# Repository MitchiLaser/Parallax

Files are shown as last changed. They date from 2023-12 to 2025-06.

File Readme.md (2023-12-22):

# Parallax

Parallax is a cheap and simple but also powerful data acquisition system. The core of this device is a Raspberry Pi Pico which has multiple analog-to-digital converters. These can be used to measure analog voltages and stream the data directly to a PC for further processing and storing.

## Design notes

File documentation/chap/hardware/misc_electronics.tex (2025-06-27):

\section{Further electrical components and their usage}

\subsection{Voltage clamping with Diodes}

A Diode is a semiconductor device that allows current to flow in one direction only\footnote{This is technically not true because a diode can also let current flow in the opposite direction but this aspect is not necessary for the design described in this report}. When a Voltage is applied across the two terminals in the forward direction the current flows easily while in reverse direction the diode blocks current. In the forward direction current flows only if the applied voltage exceeds a threshold limit, the forward voltage, typically around $\SI{0.6}{V}$ to $\SI{0.7}{V}$ for standard silicon diodes. This also means that in forward direction a voltage has a constant voltage drop which is equal to its forward voltage.

Regularly a diode can be used to prevent large voltage spikes from damaging sensitive electronic components, either by clamping the voltage to a safe level or by redirecting the current away from sensitive parts of the circuit. This is often done in power supply circuits to protect against overvoltage conditions. \cref{fig:clamping-diodes} illustrates this: When the signal line is below $\SI{0}{V}$ current flows directly to ground from $D_2$. Similar, when the signal line exceeds the supply voltage $V_{cc}$, $D_1$ conducts. However this only works when the input impedance of the device $U_{out}$ is connected to is lower than the resistance across the diode. This clamping actions maintains the voltage within a defined range.

\begin{figure}[htb]
	\centering
	\begin{tikzpicture}
		\draw (0,0) node[ground] {} 
			to[sV, l=$U_{in}$] ++ (0,2)
			-- ++ (0.5,0)
			-- ++ (2,0) node {$\bullet$} coordinate (A)
			to[short, -o] ++ (1,0) node[right] {$U_{out}$}
			(A) to[Do, l=$D_1$] ++ (0,2)
			node[vcc] {$V_{cc}$}
			(A) ++ (0,-2) node[ground] {}
			to[Do, l=$D_2$] (A)
		;
	\end{tikzpicture}
	\caption{A visualisation of the usage of clamping diodes}
	\label{fig:clamping-diodes}
\end{figure}

There is one disadvantage when this circuit is build with normal diodes: The voltage between the two terminals must be greater than the forward voltage. In this Example the voltage can only be clamped between $\SI{-0,7}{V}$ and $V_{cc} + \SI{0,7}{V}$. Diodes with a smaller forward voltage reduce this gap and here Schottky diodes are the better choice. Normal diodes are build by combining a p-type and a n-type doped semiconductor. Schottky diodes are just a combination of a doped semiconductor and a raw piece of metal. This construction has faster switching times and lower forward voltages, down to $\SI{0,3}{V}$.

After some more thinking the clamping didoes were removed from the design for the following reasons:
\begin{itemize}
	\item The clamping didoes chosen for this design were Schottky diodes. Unfortunately these have a relatively high leakage current which messes up the measurement for the smallest input range.
	\item The input current maximum rating of the ADC is only exceeded for input voltages larger than \SI{300}{V}, which should never happen under normal operating conditions. For ESD protection, the Op-Amp's internal clamping diodes are sufficient.
	\item The ADC's input cannot exceed the supply voltage $V_{cc}$ and $GND$ of the Op-Amp.
\end{itemize}

\subsection{Analog Multiplexers}

An analog multiplexer is an electronic component acting like a switch, routing multiple signals and a common input or output. Only one of the terminals can be connected at a time. Selection occurs via input signal lines which determine the connected terminal by the binary representation of its terminal number.

On the oscilloscope a multiplexer switches between resistors which are connected to ground. This makes the gain of a non-inverting amplifier variable across pre-defined configurations.

\subsection{Low pass filters}

A low pass filter is a combination of a resistor and a capacitor as depicted in \cref{fig_lowpass}. When a high frequency signals comes into this circuit form the left side then the capacitor is charged. This results in a smothering of the input signal. A low frequency signal gets less distorted than a high frequency signal.

\begin{figure}[htb]
	\centering
	\begin{tikzpicture}
		\draw (0,0) -- ++ (0.5,0)
			to[resistor, l=$R$] ++ (2,0)
			-- ++ (0.5,0)
			to[capacitor, l=$C$, *-] ++ (0,-1.5)
			node[ground] {}
			++ (0,1.5) -- ++ (1,0)
		;
	\end{tikzpicture}
	\caption{Low-Pass filter}
	\label{fig_lowpass}
\end{figure}

This circuit can be used to filter out some high frequency parts of a signal above the cutoff frequency:
\[
f = \frac{1}{2 \cdot \pi \cdot R \cdot C}\,.
\]
A low pass filter is going to be used to remove unwanted higher order frequency components of the input signal and removes aliasing effects. The reason for them is the Nyquist-Shannon theorem which in simple terms says that the highest with an oscilloscope measurable frequency is half of the sampling rate.

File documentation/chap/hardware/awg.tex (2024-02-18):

% todo: This document was not cheak-read yet.
\section{Signal Generator}

The Data Acquisition system should be extended by a arbitrary waveform generator which consists of a Digital to Analog Converter (DAC) and an amplification stage. This can be used to generate arbitrary signals: Sine-waves, triangular or rectangular periodical voltages with an adjustable frequency and amplitude. This enables students to explore and understand concepts in waveform generation, frequency modulation and signal processing and enhances the oscilloscope with a signal source. Many lab curse experiments can benefit from that e.g. measuring the frequency response of RC components, inductances or analysing the behavior or transistors and op-amps.

There are multiple ways how to create a waveform generator but then main structure is made out of three components. At first a analog voltage needs to be generated by a DAC. The DAC might need a buffer to provide an output current which can be achieved by using a buffer op-amp. At this point some amplification of the signal can be used to increase or decrease the magnitude of the signal. Finally this is used to drive an output stage in order to provide enough current for practical applications. Some of these components or even combinations of them can be bought as integrated circuits whereas others can be self made from simple building blocks. Many combinations might lead to the same result but the goal of this project is to make a cheap and simple signal generator without paying too much attention at a high precision (8 Bit resolution should be enough) or driving high frequencies\footnote{Note from the author: Initially I wished for a good signal generator but in the end I decided to go this way because it is cheaper by a couple euros.}. Therefore after a long time of researching components the way to go is: Using a R2R Ladder structure to turn 8 GPIO Pins from the Raspberry Pi Pico into a DAC and finding an Op-Amp which can provide enough current to drive a $\SI{50}{\Omega}$ signal line.

\subsection{R2R-Ladder DAC}

The DAC is a self-made R2R Ladder Structure which is driven by some parallel connected GPIO Pins. A Diagram for a 4-Bit DAC can be seen in \cref{fig:r2r-ladder}.

\begin{figure}[htb]
	\centering
	\begin{tikzpicture}
		\pgfmathsetmacro{\num}{4} % number of resistor-network stages
		\pgfmathtruncatemacro{\numminusone}{\num-1}
		\pgfmathtruncatemacro{\numminustwo}{\num-2}
		\foreach \i in {0, ..., \numminustwo} {
			\draw (\i * 2,0) to[resistor, l=$2R$, *-] ++ (0,2)
			node[above] {$B_{\i}$}
				++ (0,-2) to[resistor, l=$R$] ++ (2,0)
			;
		}
		\draw (0,0) to[resistor, l=$2R$] ++ (0,-2)
			node[ground] {}
			(\numminustwo * 2 + 2,0) to[resistor, l=$2R$, *-] ++ (0,2)
			node[above] {$B_{\numminusone}$}
			++ (0,-2) to[short, -*] + (1,0)
			node[right] {$U_{DAC}$}
		;
	\end{tikzpicture}
	\caption{R2R Ladder structure for a 4-Bit DAC}
	\label{fig:r2r-ladder}
\end{figure}

A detailed explanation how this DAC is working would take away some pages in this document so this explanation is going to cover only a rough overview. Any of the inputs $U_x$ can be set to a logical $1$ or a logical $0$ which is equivalent to connect the input to the supply voltage $V_{cc}$ or GND. If only the most significant bit (most right) is set then all the other bits (on the left side) are connected to ground. The last digit ($B_0$) has two parallel resistors with a Value of $2R$ connected to ground, resulting in a Thevenin Equivalent circuit of a Grounding with a Thevenin resistance of $2R \parallel 2R = R$. After that the first resistor $R$ follows in series from where on both resistors are equivalent to $2R$. From there on the next Bit ($B_1$) is equally connected as the previous one before constructing the Thevenin Equivalent which means that the Thevenin Equivalent for all following zeroed Bits is the same. When we reach the first positive bit (in this case the highest order bit) the equivalent circuit is a voltage divider from $V_{cc}$ (the positive bit) to Ground via two $2R$ resistors and this results in an output voltage of $U_{DAC} = V_{cc} \cdot \frac{2R}{2R + 2R} = \frac{V_{cc}}{2}$ and a Thevenin resistance of $R$.

Let's assume that all bits are zero except for the second largest one. In this case again all the previous zeroed bits have a Thevenin equivalent of a grounded Connection with a resistance of $2R$ (Thevenin Resistance + R in series from the ladder) and the equivalent circuit of the positive bit is, as calculated before, $\frac{V_{cc}}{2}$ for the second largest bit. Following the resistor chain now the last bit, which is set to $0$, creates a second attenuator with the resistors $2R$ in series to $2R$. This halves the voltage again to $\frac{V_{cc}}{4}$ and keeps the Thevenin resistance still at $R$.

This principle applies for all the other bits. Now we can apply the principle of superposition: All currents from the input Bits flowing towards the output sum up. The DAC output voltage can therefore be described as follows:
\[
U_{DAC} = \sum_{i = 1}^N \frac{V_{cc}}{i + 1}
\]
When all Bits are turned on for a 3-Bit DAC then the output voltage is
\[
	U_{DAC} = \frac{V_{cc}}{2} + \frac{V_{cc}}{4} + \frac{V_{cc}}{8} = V_{cc} \cdot \frac{7}{8}\,.
\]
Unfortunately a R2R ladder DAC can never generate the full supply voltage $V_{cc}$ at its output but with a higher Bit resolution the difference shrinks to a negligibly small size. The R2R ladder generates the voltage but as in all previously explained situations the important rule for resistor networks also applies here: Drawing current changes the behavior of the network. Therefore again a combination of buffers and amplifiers, especially to create a output driver with a predefined impedance.

Last but not least a low-pass filter is useful to suppress aliasing effects. The R2R ladder has an output impedance equal to $R$ so the only missing thing is to add a capacitor with the right size. To keep the output stage as simple as possible a voltage follower is made of an op-amp which can drive enough current to drive a $\SI{50}{\Omega}$ output. At a maximum voltage of $\SI{3,3}{V}$ the expected current is less than $\SI{70}{mA}$. For the frequency we can expect that in the fastest operation mode at $\SI{125}{MSps}$ a sine wave constructed from 64 samples\footnote{This is just an assumption without any technical background} stays below a frequency of $\SI{5}{MHz}$. The only challenge here is to find a device which has these capabilities (output current and unity-gain bandwidth) but is still cheap.

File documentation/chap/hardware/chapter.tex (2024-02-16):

\chapter{Hardware Design}

\input{./chap/hardware/introduction.tex}
\input{./chap/hardware/adc.tex}
\input{./chap/hardware/voltage_divider.tex}
\input{./chap/hardware/op-amp.tex}
\input{./chap/hardware/misc_electronics.tex}
%\input{./chap/hardware/awg.tex}
\input{./chap/hardware/schematics.tex}

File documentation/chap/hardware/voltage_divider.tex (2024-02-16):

\section{Voltage Divider}

One of them most important circuits in electronics is the voltage divider, depicted in \cref{fig:simple-voltage-divider}. In this circuit two resistors $R_1$ and $R_2$ are between connected in series between a voltage source $V_{cc}$ and Ground. Since it's a closed circuit there's a current flowing through the resistors and each resistor causes an individual voltage drop. Can we calculate the voltage $U_o$ between these two resistors?

It's easy to see that the current flowing in this circuit is the same for both resistors. When two resistors are connected in series their resistances add up and this total resistance can be used to calculate the current with Ohms law:
\begin{equation*}
	I = \frac{U}{R} = \frac{V_{cc}}{R_1 + R_2}\,.
\end{equation*}
We also know that the voltage drop $U_1$ across $R_1$ and the voltage drop $U_2$ across $R_2$ add up to the supply voltage: $U_1 + U_2 = V_{cc}\,$. The voltage drop across $R_2$ can be calculated using Ohm's law again because we know the current and the resistance:
\begin{equation*}
	U_2 = R \cdot I = V_{cc} \cdot \frac{R_2}{R_1 + R_2}\,.
\end{equation*}
A similar behavior can be seen for $R_1$:
\begin{equation*}
	U_1 = R \cdot I = V_{cc} \cdot \frac{R_1}{R_1 + R_2}\,.
\end{equation*}

This shows us that we can calculate the voltage $U_o = U_2 = V_{cc} - U_1$ between the resistors. It's independent of the total current and only depends on the ratio of the two resistors. It wouldn't make a difference if we use $R_1 = \SI{10}{K\Omega}, R_2 = \SI{2,2}{K\Omega}$ or $R_1 = \SI{10}{\Omega}, R_2 = \SI{2,2}{\Omega}$, the result would be the same.

\begin{figure}[htb]
	\centering
	\begin{tikzpicture}
		\draw (0,0) node[ground] {}
			to[resistor, l=$R_2$, -*] ++ (0,2) coordinate (A)
			to[short, -o] ++ (1,0)
			node[auto, anchor=west] {$U_o$}
			(A) to[resistor, l=$R_1$] ++ (0,2)
			node[vcc] {$V_{cc}$}
		;
	\end{tikzpicture}
	\caption{A voltage divider made with two resistors}
	\label{fig:simple-voltage-divider}
\end{figure}

The characteristic equation to describe a voltage divider can be seen in \cref{equ:resistive-voltage-divider}:
\begin{equation}
	\frac{U_1}{U_2} = \frac{R_1}{R_2}\,.
	\label{equ:resistive-voltage-divider}
\end{equation}

We can use this circuit to reduce a voltage but its usability as a voltage source is limited. This can be shown in \cref{fig:loaded-voltage-divider} by adding a load, in this case a resistor $R_L$. Now the total resistance of the parallel resistors $R_2$ and $R_L$ calculates to
\begin{equation*}
	R_x = R_2 \parallel R_L = \frac{1}{\frac{1}{R_2} + \frac{1}{R_L}}
\end{equation*}
and the result of this is smaller than $R_2$ and $R_L$. The load changes the voltage divider and this changes the output voltage $U_o$.

\begin{figure}[htb]
	\centering
	\begin{tikzpicture}
		\draw (0,0) node[ground] {}
			to[resistor, l=$R_2$, -*] ++ (0,2) coordinate (A)
			to[short, -o] ++ (1,0) coordinate (B)
			node[auto, anchor=west] {$U_o$}
			(A) to[resistor, l=$R_1$] ++ (0,2)
			node[vcc] {$V_{cc}$}
			(B) to[resistor, l=$R_L$] ++ (0,-2)
			to[short, -*] ++ (-1,0)
		;
	\end{tikzpicture}
	\caption{A voltage divider with load resistance}
	\label{fig:loaded-voltage-divider}
\end{figure}

A voltage divider can only be used as a voltage source if there is no load attached to it. This means we cannot use it to drive an electric device but we will later see that there is a possibility to avoid this issue.

Right now we only have discussed what happens when we have a fixed voltage $V_{cc}$ driving this circuit. With an AC supply $U = U_0 \cdot \sin(\omega \cdot t)$ the voltage divider still works the same because only $V_{cc}$ is time dependent; the resistors are constant and independent from the voltage or the frequency of $V_{cc}$ and therefore it should work the same with AC and DC current.

\begin{figure}[htb]
		\centering
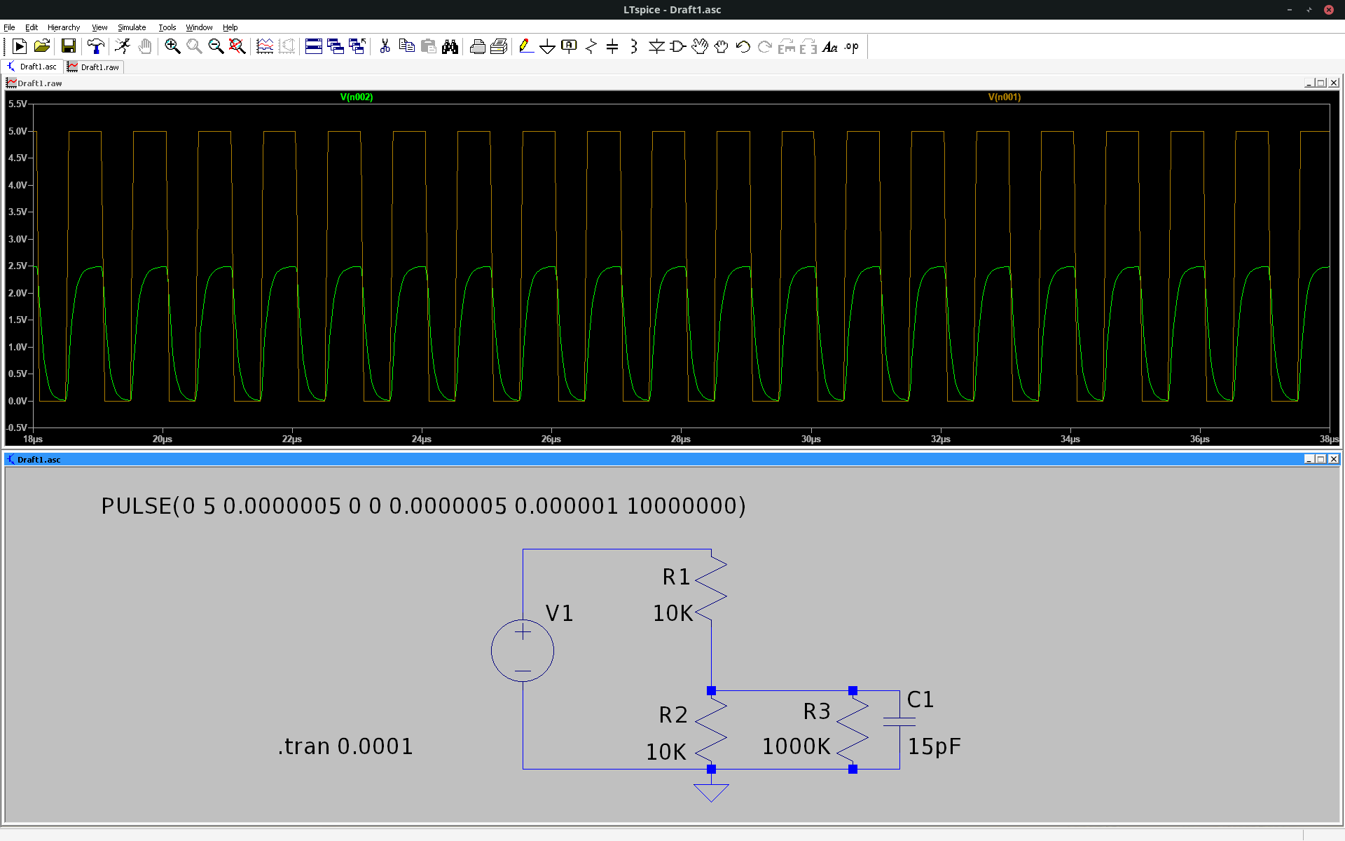
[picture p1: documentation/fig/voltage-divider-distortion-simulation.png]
		
		\caption{A square wave signal which is being disturbed by the input capacitance of an ADC}
		\label{fig:voltage-divider-distortion}
\end{figure}

Hold on! The last paragraph was partially a lie. In theory a resistor should only have a resistance but in reality every component has some resistance, capacitance and inductance. In many cases we can ignore the unwanted side-effects but when the circuit has to interact with high frequency signals these have to be taken into account. If we want to measure the voltage $U_o$ then our measurement device (which would be an ADC) has a large input resistance and a small input capacity. The large input resistance is good because ifs effect on the voltage divider can be neglected\footnote{You wanna know why? Calculate the reduction of an input voltage for a 1:1 voltage divider made out of $\SI{1}{K\Omega}$ resistors with and without an $R_L = \SI{10}{M\Omega}$ load.} but the small input capacitance would introduce a new side effect on this circuit. \cref{fig:voltage-divider-distortion} is a simulation of a square signal which will be distorted by the small input capacitance ($C_1 = \SI{15}{pF}$) of a measurement device (The large input resistance $R_3 = \SI{1}{M\Omega}$ was also taken into account in this simulation). Before we discuss how to deal with this side effect we will take a look on a voltage divider which is especially build for AC currents.

\subsection{The capacitive voltage divider}

For a DC voltage a capacitor is an impervious barrier but for an AC voltage the capacitor behaves like an electrical conductor which induces a phase shift of $\SI{90}{\degree}$. If we arrange two capacitors as seen in \cref{fig:capacitive-voltage-divider} and have an alternating voltage $\sim V_{cc}$ we can observe a similar behavior as with the resistor-based voltage divider in \cref{fig:simple-voltage-divider}.

\begin{figure}[htb]
	\centering
	\begin{tikzpicture}
		\draw (0,0) node[ground] {}
			to[C, l=$C_2$, -*] ++ (0,2) coordinate (A)
			to[short, -o] ++ (1,0)
			node[auto, anchor=west] {$U_o$}
			(A) to[C, l=$C_1$] ++ (0,2)
			node[vcc] {$\sim V_{cc}$}
		;
	\end{tikzpicture}
	\caption{A capacitive voltage divider}
	\label{fig:capacitive-voltage-divider}
\end{figure}

In this circuit the overall charge $Q$ through the capacitors is preserved:
\begin{equation*}
	Q = C \cdot U = C_1 \cdot U_1 = C_2 \cdot U_2\,
\end{equation*}
where $U_1$ and $U_2$ are the voltage drops across the capacitors $U_1$ and $U_2$. With the overall capacity of two capacitors in series:
\begin{equation*}
	C_x = \frac{1}{\frac{1}{C_1} + \frac{1}{C_2}} = \frac{C_1 \cdot C_2}{C_1 + C_2}
\end{equation*}
and the use of $Q = C_x \cdot V_{cc} = C_2 \cdot U_2$ the voltage $U_2$ drop across $C_2$ can be calculated:
\begin{equation*}
	U_2 = U_0 \frac{Q}{C} =  \frac{V_{cc}}{C_2} \cdot C_x = \frac{V_{cc}}{C_2} \cdot \frac{C_1 \cdot C_2}{C_1 + C_2} = V_{cc} \cdot \frac{C_1}{C_1 + C_2}
\end{equation*}
From symmetric reasons the equation for $U_1$ looks similar:
\begin{equation*}
	U_1 =  V_{cc} \cdot \frac{C_2}{C_1 + C_2}
\end{equation*}

From this the characteristic equation of the capacitive voltage divider is \cref{equ:capacitive-voltage-divider}

\begin{equation}
	\frac{U_1}{U_2} = \frac{C_2}{C_1}\,.
	\label{equ:capacitive-voltage-divider}
\end{equation}

With this knowledge we can build a voltage divider for AC signals but it cannot be used for DC voltages. Like a resistive voltage divider a capacitive one also only works when there is no load attached. A load can also be seen as an additional capacitor, similar to \cref{fig:loaded-voltage-divider}, which changes the capacitance ration and affects the voltage drop.

\subsection{Frequency compensated attenuator}

A resistive attenuator can only be used properly with DC voltages or AC voltages at low frequencies and a capacitive attenuator can be used with alternating voltages at high frequencies but is unusable for DC voltages. The solution to achieve both within a single circuit is called a "Frequency compensated attenuator" (\textit{attenuator} is just another name for a voltage divider).

\begin{figure}[htb]
	\centering
	\begin{tikzpicture}
		\draw (0,0) node[ground] {}
			to[short, *-] ++ (-2,0)
			to[resistor, l=$R_2$] ++ (0,2) coordinate (A)
			to[resistor, l=$R_1$, *-] ++ (0,2)
			-- ++ (2,0)
			node[vcc] {$V_{cc}$}
			to[short, *-] ++ (0,0)
			to[C, l=$C_1$, -*] ++ (0,-2) coordinate (B)
			to[C, l=$C_2$, -*] ++ (0,-2)
			-- ++ (-1,0)
			(B) ++ (2,0) coordinate (C)
			to[vC, l=$C_T$, *-] ++ (0,-2)
			to[short, -*] ++ (-2,0)
			(A) to[short] (B)
			to[short] (C)
			to[short, -o] ++ (1,0)
			node[auto, anchor=west] {$U_o$}
		;
	\end{tikzpicture}
	\caption{A frequency compensated attenuator with an adjustable capacitor for fine tuning}
	\label{fig:frequency-compensated-attenuator}
\end{figure}

The attenuator in \cref{fig:frequency-compensated-attenuator} is just a combination of a resistive voltage divider for DC signals and a capacitive voltage divider for AC signals in parallel. By using resistors which are way smaller than the load resistance of a measurement device the load would not affect this attenuator. The same thing happens when the capacitors are chosen large enough: a small load capacity would not effect the attenuator. There is also a trimmer capacitor which will be discussed later.

Let's take a look at the behaviour of this voltage divider first. We know the descriptive formulas of the previously discussed voltage dividers:
\begin{equation*}
	\frac{U_1}{U_2} = \frac{R_1}{R_2} = \frac{C_2}{C_1}
\end{equation*}
This means that a frequency compensated attenuator needs to fulfill the following requirements:
\begin{equation}
	R_1 \cdot C_1 = R_2 \cdot C_2\,.
	\label{equ:frequency-compensated-attenuator}
\end{equation}
This equation is essential for choosing the right components. One missing detail lies in the trimmer capacitor. Its only task is to compensate uncertainties of the components or other side effects which have not been taken into account. This trimmer capacitor can be set to its proper value in a calibration process until \cref{equ:frequency-compensated-attenuator} is satisfied. To do so the attenuator needs to be driven by a square signal. During a recording of $U_o$ the trimmer capacitor needs to be adjusted until the results show a pure square signal with no distortions.

\subsection{Adding voltages}

In \cref{fig:simple-voltage-divider} the voltage divider was constructed in a way where the second resistor was connected to ground. This makes it easy to calculate $U_o$ which is the voltage drop across $R_2$ added to the electrical potential at the other side of the resistor: $U_o = U_{Gnd} + U_2\,$. Since the grounding is just a fixed value for a potential this could also be set to an arbitrary value above or below Ground and the voltage divider would still work on the potential difference across the two resistors. We are going to abuse this effect to shape the output signal of the attenuator.

An ADC can only convert voltages from $\SI{0}{V}$ up to a reference voltage $U_{ref}$. To accept higher voltages than $U_{ref}$ an attenuator can be used to reduce the voltage by a factor which is specified by the resistor ratio. For voltages below the Ground of the ADC the only option is to shift the voltage up by adding a DC offset. Replacing the Ground potential at the attenuator with a Voltage source makes this voltage addition possible.

\begin{figure}[htb]
	\centering
	\begin{tikzpicture}
		\draw (0,0) node[vcc] {$V_+$}
			-- ++ (-1,0)
			to[resistor, l=$R_2$, -*] ++ (0,2) coordinate (A)
			to[short, -o] ++ (1,0)
			node[auto, anchor=west] {$U_o$}
			(A) to[resistor, l=$R_1$] ++ (0,2)
			-- ++ (1,0)
			node[vcc] {$V_{in}$}
		;
	\end{tikzpicture}
	\caption{Using an attenuator to add a DC offset to an input voltage}
	\label{fig:attenuator-voltage-adder}
\end{figure}

\cref{fig:attenuator-voltage-adder} is a schematic of this idea. This also works with a capacitive attenuator but for simplicity the calculations will only be done for a resistive attenuator. The overall voltage across both resistors has now changed from $V_{cc} - GND = V{cc} - \SI{0}{V} = V_{cc}$ to the new voltage $U = U_{in} - U_+$. The voltage drop across both resistors stays the same as before, just the input voltage needs to be replaced in this formula:
\begin{equation*}
	U_2 = U \cdot \frac{R_2}{R_1 + R_2} = (U_{in} - U_+) \cdot \frac{R_2}{R_1 + R_2}
\end{equation*}
but $U_2$ is only the voltage drop across $R_2$. We know that the electrical potential has a value of $U_+$ after the current coming from the input signal has passed $R_2$ and we know that it lost a voltage of $U_2$ on its way through $R_2$:
\begin{align*}
	U_o &= U_+ + U_2 = U_+ + (U_{in} - U_+) \cdot \frac{R_2}{R_1 + R_2} \\
		&= U_{in} \cdot \frac{R_2}{R_1 + R_2} + U_+ \left(1 - \frac{R_2}{R_1 + R_2}\right) \\
		&= U_{in} \cdot \frac{R_2}{R_1 + R_2} + U_+ \cdot \frac{R_1}{R_1 + R_2}\,.
\end{align*}
We have shown that this change to the attenuator adds a DC offset of $U_+ \cdot \frac{R_1}{R_1 + R_2}$ to the output voltage $U_0$. This can be used to transform an AC input signal from $\pm U_{in}$ to a range between $\SI{0}{V}$ and the reference voltage $U_{ref}$ of an ADC which makes the signal $\pm U_{in}$ measurable with an ADC. If we want to realise this idea we need to calculate the right values for the resistors and $U_+$.

For our usage we assume that we want to combine an attenuator with a reference Voltage $U_+$ to transform input signals from $\pm{}U_{in}$ which are way above and below the input range of an ADC into a measurable range from $\SI{0}{V}$ to $U_{Aref}$. We want to calculate the right resistor values and reference voltage for a given $\pm{}U_{in}$ and $U_{Aref}$. Therefore we have to take a look at the two cases $+U_{in}$ and $-U_{in}$ where the output voltage of the attenuator should match $U_{Aref}$ and $\SI{0}{V}$.

In the first case we want the maximum value $+U_{in}$ to be mapped to $U_{Aref}$:
\begin{align}
	U_{Aref} &= \lvert U_{in} \rvert \cdot \frac{R_2}{R_1 + R_2} + U_+ \cdot \frac{R_1}{R_1 + R_2} \\
	U_+ \cdot \frac{R_1}{R_1 + R_2} &= U_{Aref} - \lvert U_{in} \rvert \cdot \frac{R_2}{R_1 + R_2}
\end{align}
and in the second case the minimum value $-U_{in}$ to be equal to Gnd:
\begin{align}
	\text{Gnd} &= - \lvert U_{in} \rvert \cdot \frac{R_2}{R_1 + R_2} + U_+ \cdot \frac{R_1}{R_1 + R_2} \\
	U_+ \cdot \frac{R_1}{R_1 + R_2} &= \text{Gnd} + \lvert U_{in} \rvert \cdot \frac{R_2}{R_1 + R_2} = \lvert U_{in} \rvert \cdot \frac{R_2}{R_1 + R_2}\,.
	\label{equ:attenuator_with_offset_derivation}
\end{align}
For simplicity we set Ground to $\SI{0}{V}$ and we can combine the equations:
\begin{align}
	\lvert U_{in} \rvert \cdot \frac{R_2}{R_1 + R_2} &= U_{Aref} - \lvert U_{in} \rvert \cdot \frac{R_2}{R_1 + R_2} \\
	2 \cdot \lvert U_{in} \rvert \cdot \frac{R_2}{R_1 + R_2} &= U_{Aref} \\
	2 \cdot \lvert U_{in} \rvert &= U_{Aref} \cdot \frac{R_1 + R_2}{R_2} = U_{Aref} \cdot \left( \frac{R_1}{R_2} + 1 \right) \\
	2 \cdot \frac{\lvert U_{in} \rvert}{U_{Aref}} &= \frac{R_1}{R_2} + 1 \\
	\frac{R_1}{R_2} &= \frac{2 \cdot \lvert U_{in} \rvert}{U_{Aref}} - 1\,.
\end{align}
This equation shows us that, independent from the voltage shift we can choose a value for one resistor and get the implicit value for the other resistor. The value for the voltage shift can be calculated after the resistor values have been selected. This will be shown with a modification of \cref{equ:attenuator_with_offset_derivation}:
\begin{align}
	U_+ \cdot \frac{R_1}{R_1 + R_2} &= \lvert U_{in} \rvert \cdot \frac{R_2}{R_1 + R_2} \\
	U_+ &= \lvert U_{in} \rvert \cdot \frac{R_2}{R_1 + R_2} \cdot \frac{R_1}{R_1 + R_2} \\
			&= \lvert U_{in} \rvert \cdot \frac{R_2}{R_1}\,.
\end{align}
With these equations we can easily choose the right values for the resistors and the offset voltage when we have decided on the input voltages we want to measure with an ADC. The offset voltage can be provided with an Operational Amplifier.

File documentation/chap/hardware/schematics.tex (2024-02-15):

\section{Designing the schematics}

The whole Schematics can be seen in %\cref{}
. Each major component is treated as a submodule which will be explained in detail individually.

\todo[inline]{Add picture and explaination of main structure}

\subsection{Analog Front-End}

The analog front-end is responsible for the following operations:
\begin{itemize}
	\item \textbf{Signal Coupling}: The front-end may offer different coupling options such as AC coupling or DC coupling. AC coupling blocks DC components of the signal, allowing only the AC portion to be displayed. DC coupling allows both AC and DC components to be displayed.
	\item \textbf{Signal attenuation}: The input signal might be in a range too large for the ADC. Attenuation circuits  reduce the magnitude of the incoming signal to a level that can be properly processed.
	\item \textbf{Signal amplification}: The analog front-end includes an amplifier stage to increase the magnitude of small signals. This amplification is necessary to ensure that small signals can be accurately measured.
	\item \textbf{Input Range selection}: To achieve a good measurement quality the attenuation and amplification can be varied depending on a selected input range. This input range is going to be mapped to the voltages which are suitable for the ADC.
	\item \textbf{Clamping}: Clamping diodes fix the maximum and minimum voltage level of the input signals and saves electrical components from dangerous voltages. Furthermore they are a good ESD protection for the circuit.
	\item \textbf{Signal Filtering}: In order to keep the input signals within the Nyquist frequency range a low-pass filter reduces aliasing effects.
	\item \textbf{Input impedance matching}: It's crucial for the oscilloscope to present a high input impedance to the circuit under test to minimize loading effects. The front-end typically ensures impedance matching to prevent distortion of the measured signal due to the oscilloscope's presence in the circuit.
	\item \textbf{Calibration}: Some parts of the circuit may compensate for any inaccuracies introduced by the analog components or variations in manufacturing.
\end{itemize}

At first some global decisions have to be made: Which input ranges (and how many) are going to be available.

\todo[inline]{Explain how the schematics diagram works, how all values were calculated and why some test pins were placed on their locations. Maybe also write something about the pcb layout?}

\todo[inline]{Design the PCB in a way that the backside has no electronic parts but a silk screen of all the schematics (mirrored) and all the test points should also be on this side}

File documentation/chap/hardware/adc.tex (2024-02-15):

\section{Measuring analog voltages}

The main part of the data collection process is the PR2040 Microcontroller, which has built-in Analog-to-Digital Converters (ADCs). These ADCs convert electronic voltages ranging from Ground ($\SI{0}{V}$) to a reference voltage $U_{ref}$ into digital numbers, with a resolution set to 12 bits. This means the digital result from an ADC falls between $0$ and $2^{12} = 4096$. In theory this mapping should be proportional but in practise there are small uncertainties in this conversion process due to the resolution, as depicted in \cref{fig:ADC-Curve}. This figure shows that the uncertainty of a value acquired by an ADC is half the voltage corresponding to the least significant bit (LSB), which can be calculated as:

\begin{equation*}
	\sigma = \pm{} U_{ref} \cdot \frac{1}{2} \cdot \frac{1}{2^{resolution}} = \pm{} U_{ref} \cdot 2^{-(resolution + 1)}\,.
\end{equation*}

\begin{figure}[htb]
		\centering
		
		\caption{Conversion from an analog voltage do a digital number with an ADC}
		\label{fig:ADC-Curve}
\end{figure}

In practice, there are further reasons for short-term fluctuations in voltage which are bigger than the quantization uncertainty. Therefore, the proper uncertainty of an ADC in an electronic application can be determined through a  calibration process. A detailed explanation and characterisation of the Raspberry Pi Picos ADCs is available on \href{http://pico-adc.markomo.me/}{this website}.

The \href{https://datasheets.raspberrypi.com/rp2040/rp2040-datasheet.pdf}{data sheet} explains that four ADC channels (ADC0 to ADC3) are connected to GPIO Pins and the fifth ADC channel (ADC4) is connected to an internal temperature sensor. Notably the fourth channel ADC3 is connected to an onboard attenuator. This configuration is intended to be used to measure the VSYS voltage of the Raspberry Pi Pico board.

Each channel is linked to a single Analog-to-Digital Converter (ADC) through an internal switch, allowing the selection of one channel at a time. The shared ADC operates with a maximum sampling rate of 500 kilosamples per second (KSps). This sampling rate can be utilized for measuring voltages on a single channel at the full sampling speed (simplex). Alternatively, it can simultaneously measure two channels by periodically switching between them, effectively halving the sampling rate to 250 KSps per channel. The level of accuracy and sampling rate is sufficient for using the system as the core of a simple oscilloscope which periodically acquires ADC values and streams the data to another device for further processing.

An ADC can only measure voltages between $\SI{0}{V}$ and $U_{ref}$ but we aim to build an oscilloscope capable of measuring both positive and negative voltages within a range, for instance, $\vert U \vert > \SI{10}{V}$. To achieve this, an analog front-end is needed to map voltages from $-U_{max}$ to $+U_{max}$ into an analog voltage suitable for the ADC. Furthermore the input voltage range should be adjustable and there should be an over-voltage protection on the signal inputs. This allows for the measurement of higher voltages with less precision or lower voltages with higher precision.

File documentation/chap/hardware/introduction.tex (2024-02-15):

\section{Introduction}

This part explains how the measurement system's hardware works. It aims to make it clear why and how the hardware was designed. Basically, the hardware is meant to convert analog voltages with a high amplitude into smaller ones. Then, we can measure these smaller voltages using the PR2040 Microcontroller on the Raspberry Pi Pico Microcontroller board.

\subsection{Prerequisites}

Before we talk about how the analog front-end works and the different voltage ranges for the oscilloscope, you need to know some basics about electronics. This includes:

\begin{itemize}
	\item Understanding what Charge, Voltage, and Current are
	\item Knowing about electrical resistance, Ohm's Law, and how resistors work
	\item Learning about Capacitance and capacitors
	\item Knowing how to use a Diode and a Z-Diode
\end{itemize}

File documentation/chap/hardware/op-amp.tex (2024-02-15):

\section{Operational Amplifier}

Operational Amplifiers, or op-amps, are highly used active electronic component\footnote{Active components need a supply voltage whereas passive components don't need a connection to a power supply} due to their versatility. In this section only the topics relevant for the application of this project are discussed. Let's take a look at the operational amplifier in \cref{fig:op_amp}: It has two inputs, namely an inverting and a non-inverting one, along with an output.

\begin{figure}[htb]
	\centering
	\begin{tikzpicture}
		\draw (0,0) node[op amp] (opamp) {}
			(opamp.+) -- + (-0.5,0) node[left] {$U_+$}
			(opamp.-) -- + (-0.5,0) node[left] {$U_-$}
			(opamp.out) -- + (0.5,0) node[right] {$U_{out}$}
			(opamp.up) -- + (0,0.5) node[vcc] {$V_{cc}$}
			(opamp.down) -- + (0,-0.5) node[vee] {$V_{ee}$}
		;
	\end{tikzpicture}
	\caption{Operational Amplifier}
	\label{fig:op_amp}
\end{figure}

Op-amps are being used in a configuration where the output voltage is connected to an input which creates a feedback loop. The behavior of am ideal operational amplifier can be described by the \glqq{}golden Rules\grqq{}:
\begin{enumerate}
	\item No current flows into the inputs.
	\item The output strives to minimize the voltage difference between the two input pins to zero volts.
\end{enumerate}

These rules only apply within a feedback loop. It's important to notice that the first rule is just an approximation because the input resistance cannot be infinitely high, resulting in an input bias current in reality. We assume that this is true in our model to describe the functionality of an op-amp and for practical applications the input impedance can be looked up in the data sheet. There are two op-amp circuits being used for the oscilloscope: the voltage follower and the non-inverting amplifier.

\subsection{Op-Amp as a Voltage follower}

The voltage follower configuration, illustrated in \cref{fig:voltage-follower}, serves as an impedance converter or as a buffer.

\begin{figure}[htb]
	\centering
	\begin{tikzpicture}
		\draw (0,0) node[op amp] (opamp) {}
			(opamp.out) -- ++ (0.5,0) node[right] {$U_{out}$}
			(opamp.up) -- ++ (0,0.5) node[vcc] {$V_{cc}$}
			(opamp.down) -- ++ (0,-0.5) node[vee] {$V_{ee}$}
			(opamp.-) -- ++ (-0.5,0) node[left] {$U_-$}
			-- ++ (0,2)
			-| (opamp.out) node {$\bullet$}
			(opamp.+) ++ (-0.5,-1.5) node[ground] (gnd) {}
			(opamp.+) -- ++ (-0.5,0) node[left] {$U_+$}
			-- ++ (0,-0.5)
			to[sV, l_=$U_{in}$] (gnd)
		;
	\end{tikzpicture}
	\caption{Op-Amp as a Voltage follower}
	\label{fig:voltage-follower}
\end{figure}

In this setup, the output voltage mirrors the input voltage, serving as a buffer. The high input impedance of the op-amp enables voltage replication without drawing significant current from the source, while the low output impedance ensures efficient transmission of the replicated voltage.

An example illustrates the significance of this buffer: a voltage divider generates a reference voltage, but using it as a direct voltage source is impractical due to the voltage drop when attaching a load. Using a voltage follower, as shown in Figure \ref{fig:attenuator-buffer}, solves this issue and allows the voltage follower to supply current while maintaining an output voltage equivalent to the voltage divider's reference voltage. In this sketch the power supply connections of the op-amp have been left out. This is done a lot of times in circuits because the connection to a power supply is necessary for an op-amp and therefore has not to be specialised separately.

\begin{figure}[htb]
	\centering
	\begin{tikzpicture}
		\draw (0,0) node[op amp] (opamp) {}
			(opamp.-) -- ++ (0,1)
			-| (opamp.out) node {$\bullet$}
			-- ++ (0.5,0) node[right] {$U_{out}$}
			(opamp.+) -- ++ (-1,0) node {$\bullet$} coordinate (A)
			to[resistor, l=$R_1$] ++ (0,2) node[vcc] {$V_{cc}$}
			(A) ++ (0,-2) node[ground] {} to[resistor, l=$R_2$] (A)
		;
	\end{tikzpicture}
	\caption{Voltage follower as a buffer}
	\label{fig:attenuator-buffer}
\end{figure}

When the input voltage $V_{cc}$ is constant and has no time dependency it is recommended to add a capacitor at the non-inverting input of the op-amp. This would stabilize the voltage and filter out minor fluctuations and instabilities.

\subsection{Op-Amp as a non-inverting amplifier}

Amplification of input signals is another essential task for an op-amp. There are multiple ways to perform an amplification. Here the non-inverting amplifier circuit, represended in \cref{fig:non_inverting_amplifier} is going to be explained.

\begin{figure}[htb]
	\centering
	\begin{tikzpicture}
		\draw (0,0) node[op amp, noinv input up] (opamp) {}
			(opamp.out) -- ++ (1,0) node[right] {$U_{out}$}
			(opamp.out) ++ (0.5,0) node {$\bullet$}
			to[resistor, l=$R_1$] ++ (0,-2) node {$\bullet$} coordinate (A)
			to[resistor, l=$R_2$] ++ (0,-2) node[ground] (gnd) {}
			(A) -| (opamp.-)
			(opamp.+) -- ++ (-1,0)
			++ (0,-2) node[ground] (gnd) {}
			to[sV, l=$U_{in}$] ++ (0,2)
		;
	\end{tikzpicture}
	\caption{Op-Amp as a non-inverting amplifier}
	\label{fig:non_inverting_amplifier}
\end{figure}

How does this circuit work? Based on the rules of the ideal op-amp the inverting input voltage $U_-$ is going to match the voltage at the non-inverting input $U_+$. $U_+$ is determined by the voltage across the two resistors of the attenuator. Therefore we can set $U_0$ from \cref{fig:simple-voltage-divider} equal to the input voltage:
\begin{equation}
	U_{in} = U_{out} \cdot \frac{R_2}{R_1 + R_2}\,.
\end{equation}
This equation can be transformed to calculate $U_{out}$ based on an arbitrarily chosen $U_{in}$:
\begin{equation}
	U_{out} = U_{in} \cdot \frac{R_1 + R_2}{R_2} = U_{in} \cdot \left( 1 + \frac{R_1}{R_2} \right)\,.
\end{equation}
The amplification factor, formally known as the \glqq{}gain\grqq{}, cannot be lower than $\SI{1}{}$. For the oscilloscope this configuration can be used to amplify small signals and map them to a wider voltage range, allowing to use the full input range of an ADC for their measurement.

While the \glqq{}inverting amplifier\grqq{} circuit is more common in electronic applications, the non-inverting configuration is preferable in this project for several reasons:
\begin{itemize}
	\item The non-inverting amplifier has a higher input impedance, minimizing voltage drops when measuring analog voltages.
	\item It eliminates the need for a negative voltage source $V_{ee}$, which simplifies the circuit.
	\item The non-inverting amplifier maintains isolation between the input and output signals. This benefits makes it simple to get the overall input impedance for the signal inputs of the oscilloscope.
\end{itemize}

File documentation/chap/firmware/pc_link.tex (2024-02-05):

\section{PC communication}

\todo[inline]{write a chapter about the communication between the Raspberry Pi Pico and the PC: USB<->UART at extremely high baud rates}

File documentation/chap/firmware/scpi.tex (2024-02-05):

\section{The SCPI Protocoll}

\todo[inline]{explain the SCPI protocoll which will be evaluated on the Pico and used to transfer commands from the PC to the Oscilloscope}
\todo[inline]{Explain how the state machine in the device looks like}

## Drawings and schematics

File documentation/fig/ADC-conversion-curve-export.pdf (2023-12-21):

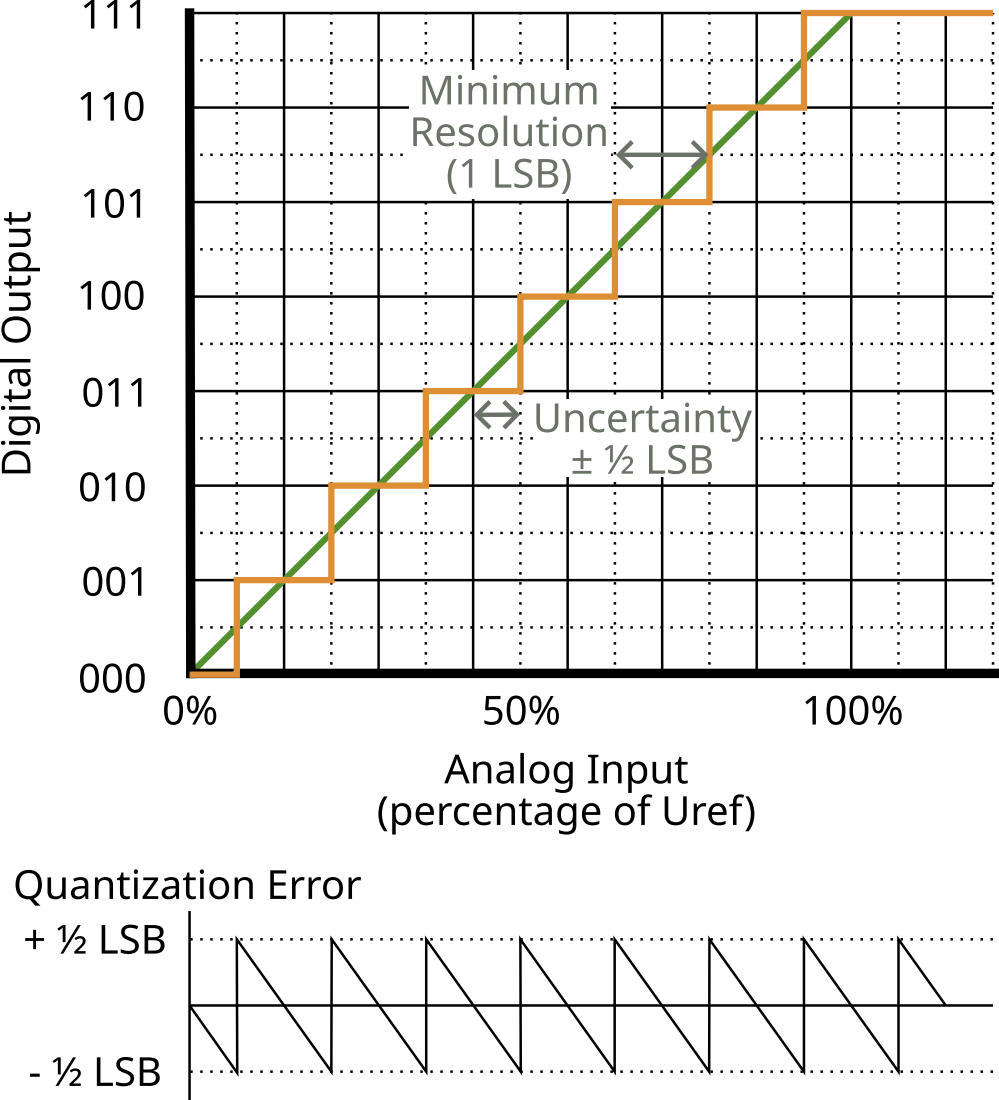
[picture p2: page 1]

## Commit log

2023-12-21 first steps in schematics design and hardware documentation introduction
    [parallax.kicad_pcb, parallax.kicad_sch]
2023-12-21 [docs] chapter about capacitive attenuator
2024-01-31 [docs] voltage adder
2024-01-31 better structure of schematics
    [afe.kicad_sch, parallax.kicad_pcb, parallax.kicad_sch]
2024-02-01 [docs] beginning op-amp circuit
2024-02-02 [docs] added chapter about clamping diodes
2024-02-06 started adding some footprints
    [afe.kicad_sch, parallax.kicad_sch]
2024-02-06 [hard] script to calculate resistor values based on defined input ranges
2024-02-07 [hard] beautified output of script to calculate resistor ratios
2024-02-07 [hard] resistor calculation: small improvement
2024-02-15 [hard] footprint assignment and some Part Ordering numbers
    [afe.kicad_sch, parallax.kicad_sch]
2024-02-16 [docs] low pass filter
2024-02-16 restructured schematics, added more symbols and also some ordering part numbers
    [awg.kicad_sch, parallax.kicad_sch]
2024-02-17 [hard] simple dac design ready, integration still missing
    [awg.kicad_sch]
2024-02-18 [awg] docs and schematics finished but integration not available
    [afe.kicad_sch, awg.kicad_sch]
2024-02-19 [hw] afe: reoriented mux so a high-impedance option is available for op-amp 2
    [afe.kicad_sch]
2025-06-20 update analog front-end and resistor calculator: Better documentation
    [afe.kicad_sch, awg.kicad_sch, parallax.kicad_sch]
2025-06-20 calculate the right resistors for the circuit and the simulation
2025-06-20 update schematics to calculated values
    [afe.kicad_sch, parallax.kicad_sch]
2025-06-26 afe and simulation ready
    [afe.kicad_sch, parallax.kicad_sch]
2025-06-27 remove clamping diodes completely
    [afe.kicad_sch]
2025-06-27 removed claping diodes from simulation
2026-01-13 started PCB routing, AFE ready, rest still in Progress
2026-02-15 Hardware: now in the state where a testing prototype can be ordered
2026-10-28 Update Trimmer Capacitor Footprint
